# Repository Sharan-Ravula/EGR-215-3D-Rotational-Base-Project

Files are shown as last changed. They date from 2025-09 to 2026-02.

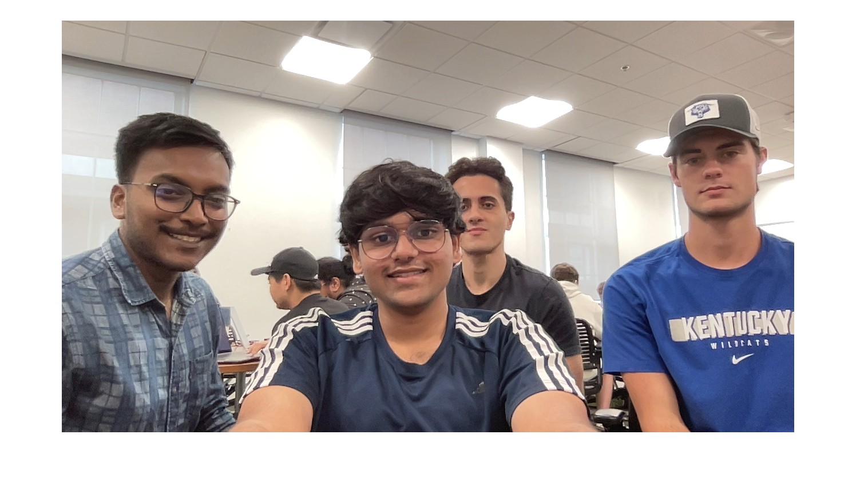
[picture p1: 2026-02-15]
team_1.jpg

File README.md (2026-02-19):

# Automated Water Sampler System

## ‼️ My First University Engineering Project

> Note: This project was developed as my first engineering design project at the University of Kentucky College of Engineering. It represents my first experience synthesizing mechanical design, electronic control, and software integration in a team environment.

An integrated hardware and software solution designed to automate the collection and distribution of liquid samples. This system focuses on the precise positioning of sample containers and the automated handling of fluids.

---

## Project Overview:

The system utilizes a rotational base to position sample cups under a stationary pipette. A motorized lift mechanism controls the vertical movement of the pipette, while a squeeze mechanism handles liquid uptake and dispensing. The entire process is orchestrated via a MATLAB GUI and Arduino microcontrollers.

---

## 📂 Repository Structure

```text
EGR-215-3D-Rotational-Base-Project/
│
├── CAD/                                         # Engineering designs and 3D models for mechanical components          		
│   ├── cad_rotational_base.pdf 		         # Technical 2D drawings and dimensions for the base
│   ├── cad_wheels.pdf                           # Technical 2D drawings and dimensions for the base
│   ├── rotational_base_2.stl                    # 3D-printable files for the main chassis components
│   ├── Rotational_base.stl                      # 3D-printable files for the main chassis components
│   ├── wheel.ai        		                 # Vector file for laser-cutting or custom fabrication of the wheels
│ 
├── docs/                               		 # Project management and analytical data
│   ├── peer_discussion_evaluation.docx          # Documentation of team collaboration and peer feedback          
│   ├── samples_performance_data.xlsx            # Testing results and performance metrics for the rotation base
│   ├── water_sampler_performance_data.xlsx      # Testing deviation errors and movement repeatability for the rotation base					
│
├── scripts/                                     # Firmware and control software     
│   ├── arduino_code.ino                         # Main C++ source code for the microcontroller to manage motor rotation and sensor triggers	
│   ├── trigger_arduino.m                        # MATLAB script used to interface with the hardware for data acquisition or remote triggering	              
│
├── team_1.png                           	     # team_1 group selfie
├── README.md                           	     # Project overview and instructions
└── LICENSE                                      # License information for the repository
```

---

## 🛠 Subsystems & Team:

- Rotational Base (`Sharan Ravula`): Design of the rotating platform, motor selection (stepper), and friction/torque analysis to ensure precise positioning ($180^\circ$ rotation and back).
  
- Stand & Lift (`Aaron Cook`): Structural support and the vertical slide mechanism powered by a servo motor.
  
- GUI (`Fayek Sharaf`): MATLAB-based interface and coordinate system movements.
  
- Pipette Squeeze (`Fernando C Tanse Mosneagu`): Motorized lever mechanism designed to provide the specific force required to compress a pipette bulb for liquid suction.

---

## ⚙️ Rotational Base Technical Specs:

> Aaron helped me a lot when building the rotational base, Thank you for that Aaron <3

- The core of the positioning system, designed to rotate samples into place with high repeatability.
  
- Hardware: Plywood base (density ~ 500 kg/$`m^3`$) driven by a 2052 steps/rev stepper motor.
  
- Design Constraints: The radius was set to 9.45 cm to balance the required torque against system stability.
  
- Friction Management: Extensive modeling was performed to map the Coefficient of Friction (CoF) against required Torque. To ensure smooth operation, the team implemented low-friction materials and load distribution strategies.

---

## ⚖️ Load Testing:

The rotational base was stress-tested with various "real-world" weights to ensure the motor did not stall:

  - Tested Weights: Successfully handled loads ranging from 24g to 160g.
    
  - Stability: Use of rubber, paper, and ball-bearing supports were iterated to maintain stability under high-weight samples.

---

## 🛠 Materials Used:

- Structure: Plywood, 3D printed gears/components, and metal bearings.
  
- Electronics: Arduino Ethernet/Uno, Stepper Motor (28BYJ-48), Servo Motor, and external power supply.
  
- Fluidics: Standard laboratory pipette.

---

## 🧪 Proof of Concept:

The project successfully met several key performance milestones:

 - Rotational Precision: The stepper motor successfully moved the platform 180 deg and returned to the home position.
   
 - Mechanical Reliability: The lift mechanism demonstrated the ability to carry the weight of the servo and pipette assembly without stalling.
   
 - Force Modeling: Calculated the specific force-to-torque ratio necessary to achieve precise 1 ml liquid draws.
   
 - MATLAB GUI: Provides the user interface and sends serial commands to the hardware.

---

## 📹 Video:

- [Team#1 Video of the Project (Team) EGR 215](https://youtu.be/eUpzdUF81iA?si=0lt0mXDnTIAIJpGk)
   
- [Rotational Base Subsystem Demonstration EGR 215](https://youtu.be/x_shSBH9O_A?si=jgN_XBuFfA_SxD8r)

---

## Team Members:

  - Sharan Ravula
    
  - Aaron Cook
    
  - Fernando C Tanse Mosneagu
    
  - Fayek Sharaf

---

> I had a lot of fun with the team when we were working on the projects and playing table tennis with Aaron



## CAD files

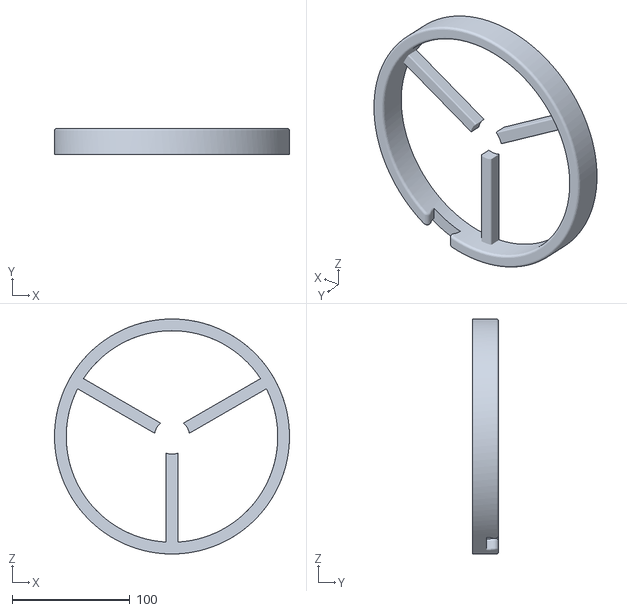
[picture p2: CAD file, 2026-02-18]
CAD/Rotational_base.stl
200.0 x 22.5 x 200.0

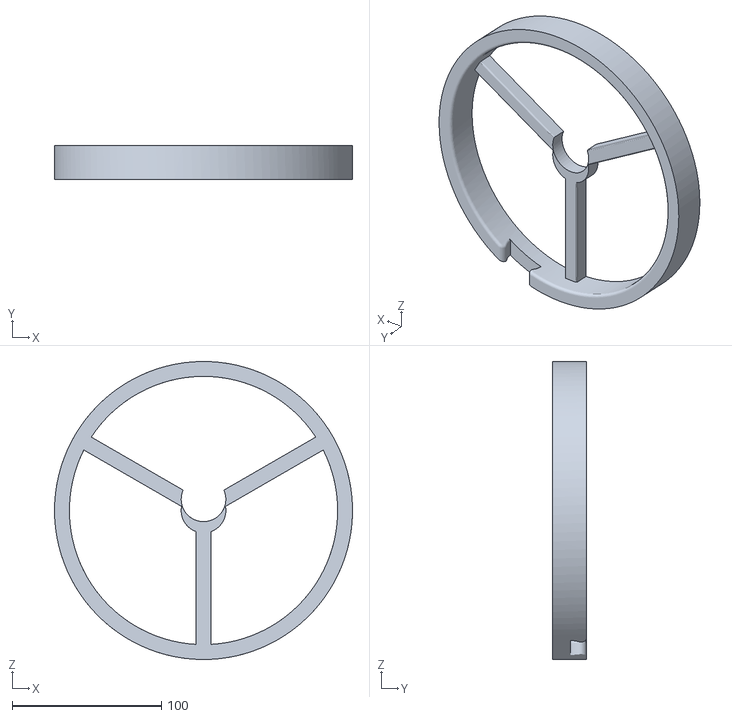
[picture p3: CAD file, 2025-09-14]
CAD/rotational_base_2.stl
200.0 x 22.5 x 200.0

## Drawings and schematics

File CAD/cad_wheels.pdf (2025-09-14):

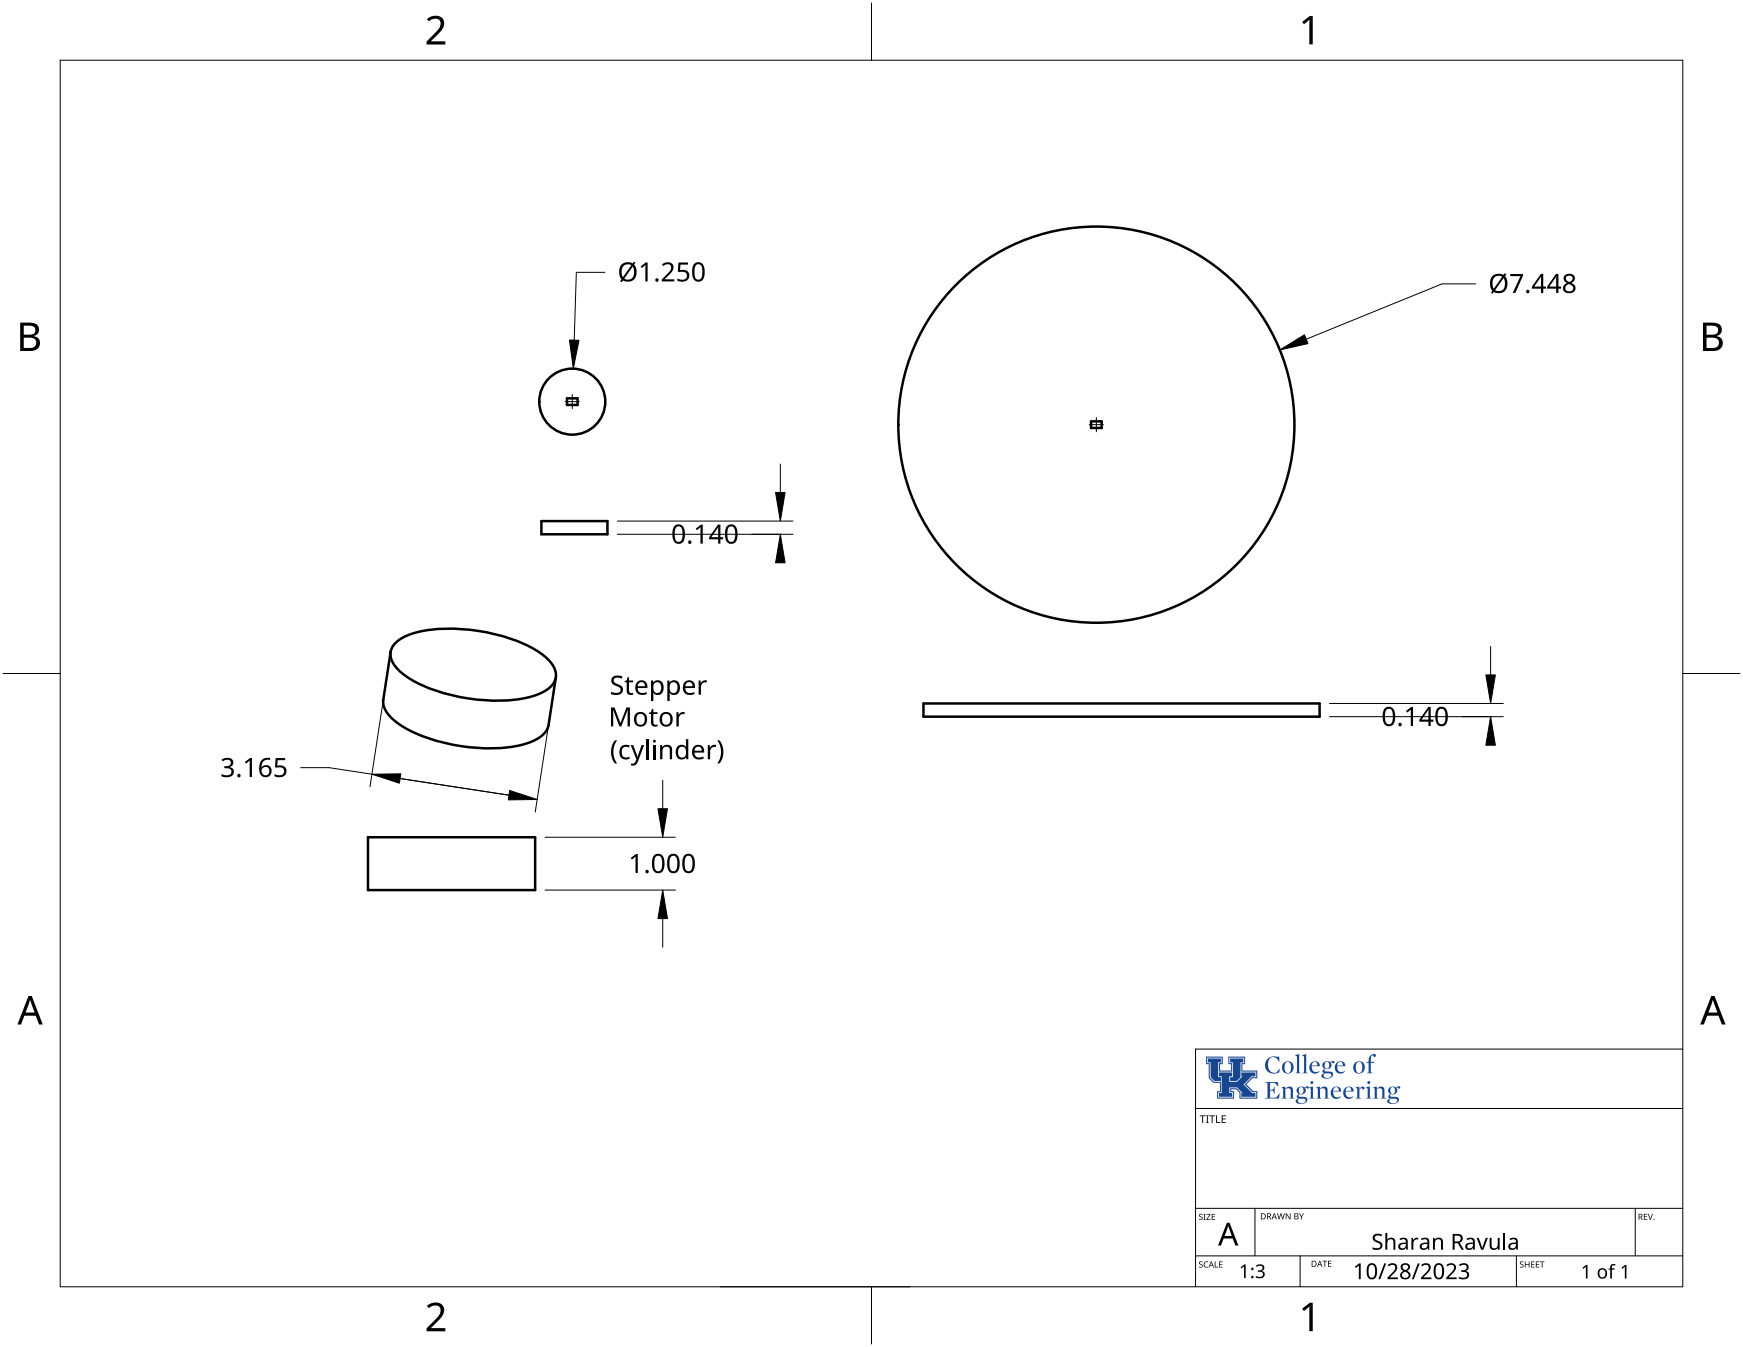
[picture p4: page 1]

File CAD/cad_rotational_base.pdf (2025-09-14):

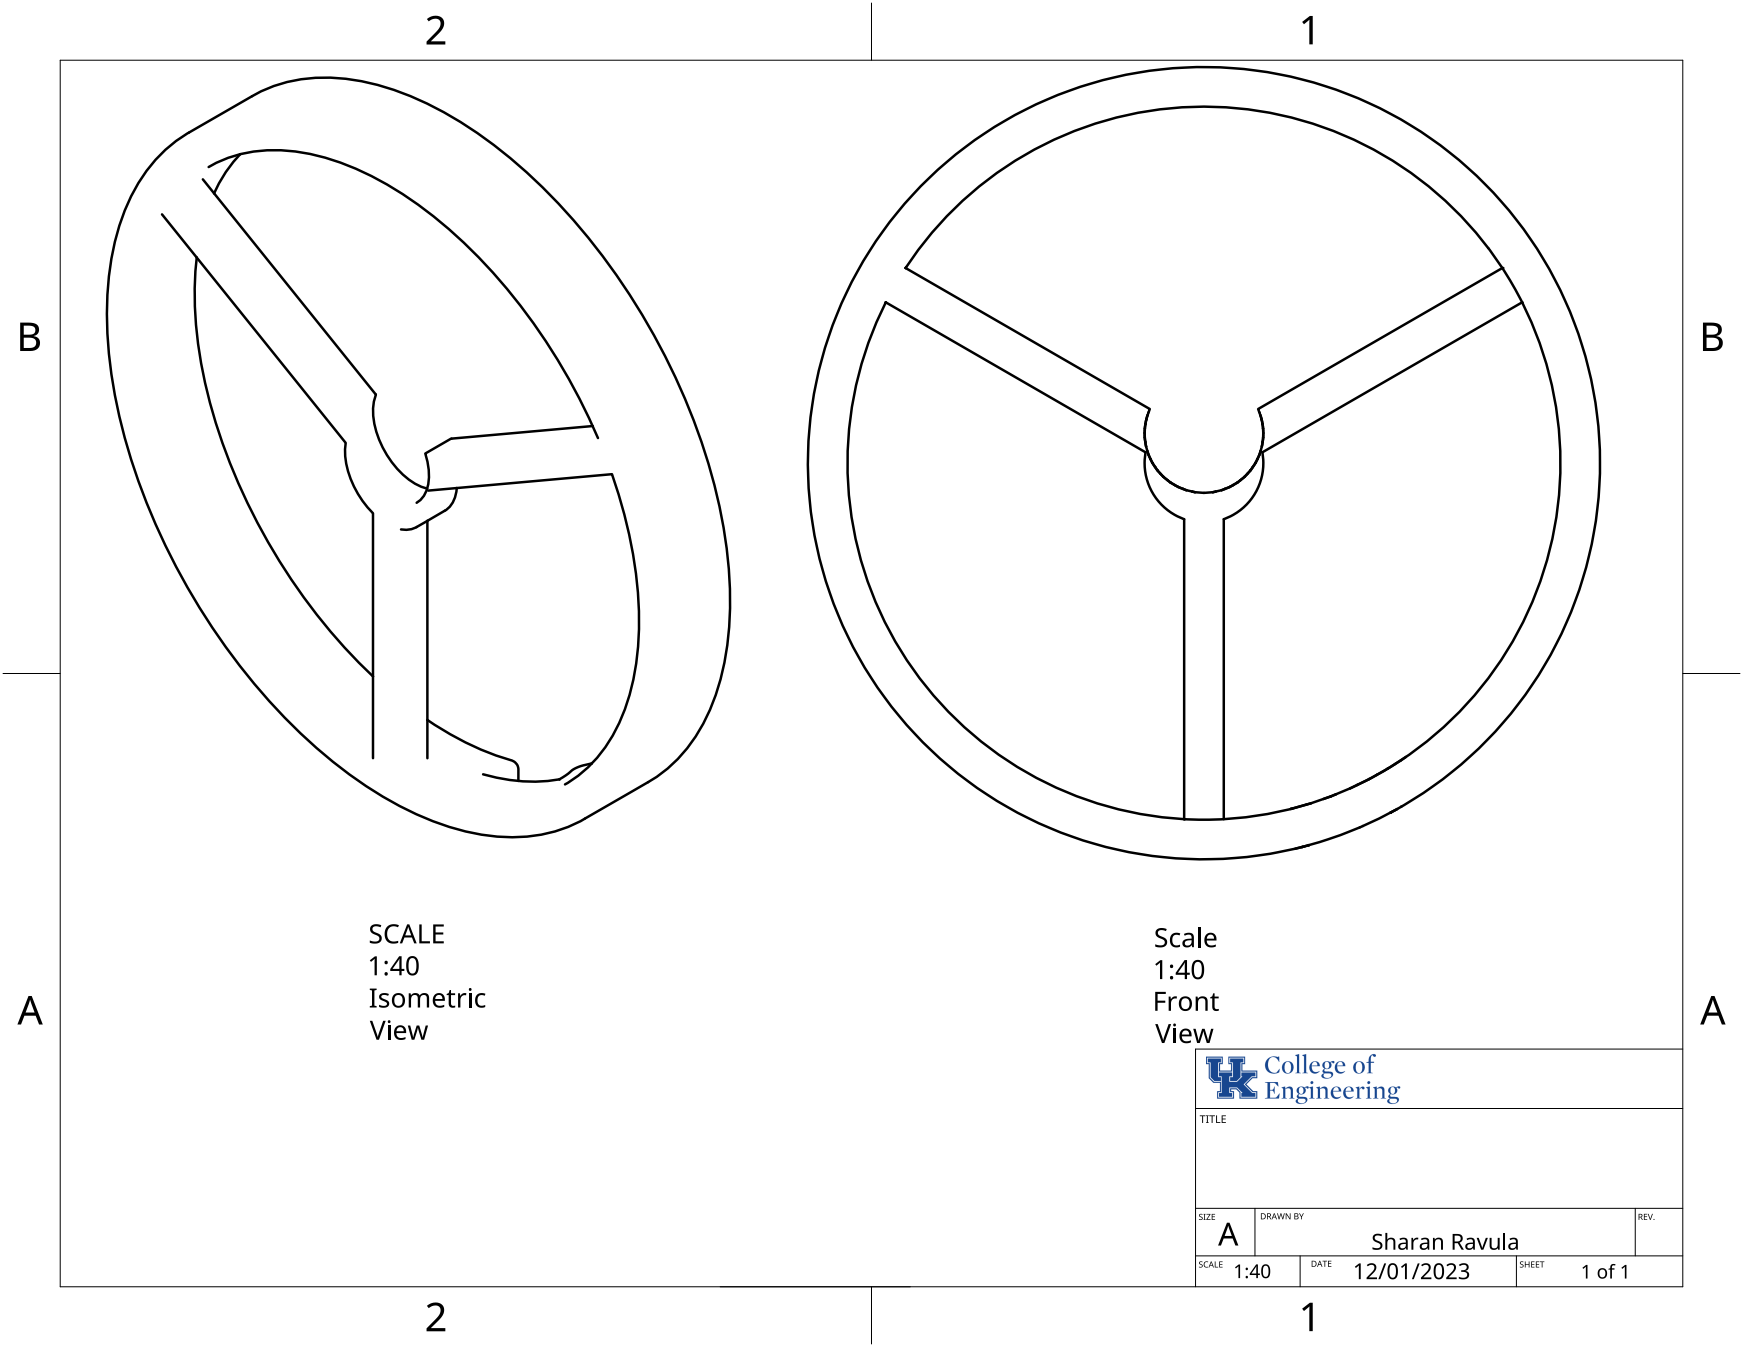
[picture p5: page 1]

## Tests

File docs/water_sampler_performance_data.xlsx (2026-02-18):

Rotational Base
Test: Movement Repeatability
Adjust the instructions below to fit your specific application |  |  | Trial 1,2,3: how to measure error distance
Goal is a numerical test of the location of the sample in front of the pipette
Start all tests from an initial and repeatable "home" position
 | RESULTS BELOW
Trial 1: Moving the sample for liquid uptake (input)
Start with the base at a location to take on a new sample. With matlab rotate the sample the expected number of degrees to bring it directly under the pipette. Record the number of distance the center of the sample cup is off from the exact center. (measurement in mm at the rotational center under the pipette) | 5
Repeat the above measurement and record here | 4
Repeat the above measurement and record here | 3
Trial 2: Movement for output 1
Start with the base at the input sample location. This is frequently done in conjunction with the measurement above. Rotate the base to the first output location. Measure the distance in mm from the ideal location. | 4
Repeat the above measurement and record here | 3
Repeat the above measurement and record here | 2
Trial 3: Movement for output 2
If there is more than 1 output position, from output position 1 (or the starting location at the input) record the accuracy in mm to get to output position 2. If there is not 2 output positions, then repeat trial 2 for three additional times. | 4 | Create a graph of your results for Tests 1-3. Scatter plots should work best for this type of data
Repeat the above measurement and record here | 3
Repeat the above measurement and record here | 2
Trial 4: Measurement/Task Accuracy
Depending on your application there is likely an additionl task/data required. In this space test the accuracy of that performance task. Where possible use a measureable result, not just yes/no. | 1
Repeat the above measurement and record here | 1
Repeat the above measurement and record here | 1
Trial 1: how much variation (range) was there in the measurements? | 2
Trial 2: what was your accuracy for an angle move? | 2
Trial 3: At the end of 3 trials was your zero any less accurate than for the first test? | 1

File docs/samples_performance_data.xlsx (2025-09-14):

Rotational Base | Samples | Sample Weight 1 | Sample Weight 2 | Sample Weight 3 | Sample Weight 4 | Total Weight | Support
Rotational_Base-1 | 2 | 12g (ballbearing) | 12g (ballbearing) | - | - | 24g | No
Rotational_Base-2 | 2 | 33g (car_keys) | 31g (ghee + 24teeth) | - | - | 64g | Yes (rubber+paper)
Rotational_Base-3 | 2 | 23g (ghee) | 33g (empty_tupperware + water) | - | - | 66g | Yes (rubber+paper)
Rotational_Base-4 | 4 | 33g (car_keys) | 21g (water) | 23g (ghee) | 33g (empty_tupperware + water) | 110g | Yes (rubber+paper)
Rotational_Base-5 | 4 | 33g (car_keys) | 21g (water) | 23g (ghee) | 33g (empty_tupperware + water) | 110g | No
Rotational_Base-6 | 4 | 33g (car_keys) | 21g (water) | 23g (ghee) | 33g (empty_tupperware + water) | 110g | No
Rotational_Base-7 | 2 | 23g (ghee) | 21g (water) | - | - | 44g | No
Rotational_Base-8 | 4 | 30g (other) | 33g (keys) | 23g (ghee) | 33g (empty_tupperware + water) | 119g | Yes (other+ball-bearings)
Rotational_Base-9 | 4 | 23g (ghee) | 33g (empty_tupperware + water) | 4g (two centangle) | 5g (two lid box + 10 teeth) | 65g | Yes (other+ball-bearings)
Rotational_Base-10 | 4 | 23g (ghee) | 33g (empty_tupperware + water) | 4g (two centangle) | 5g (two lid box + 10 teeth) | 65g | Yes (other+ball-bearings)
Rotational_Base-11 | 2 | 13g (ballbearing + stick) | 16g (others) | - | - | 29g | Yes (other+ball bearings+wallet)
Rotational_Base-12 | 4 | 23g (ghee) | 24g (two ballbearings + stick) | 21g (water) | 33g (empty_tupperware + water) | 101g | Yes (rubber+paper)
Rotational_Base-13 | 4 | 23g (ghee) | 21g (water) | 24g (two ballbearings + stick) | 26g (others) | 94g | No
Rotational_base-14 | 2 | 80g (water) | 80g (water) | - | - | 160g | Yes (rubber + paper)

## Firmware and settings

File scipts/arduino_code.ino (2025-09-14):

#include «Stepper.h>

const int stepsPerRevolution = 2052;
int rotate = 0;

Stepper myStepper = Stepper(stepsPerRevolution, 8, 10, 9, 11);

void setup() {
  Serial.begin(9600); 
  myStepper.setSpeed(10);
}

void loop() {
  if (Serial.available() > 0) {
    rotate = Serial.parseInt();
    myStepper.step(rotate);
    rotate = 0;
  }
}
